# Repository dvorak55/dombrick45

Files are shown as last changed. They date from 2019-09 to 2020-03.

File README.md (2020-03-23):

# Dombrick45 : Dvorak Oriented 45% Keyboard
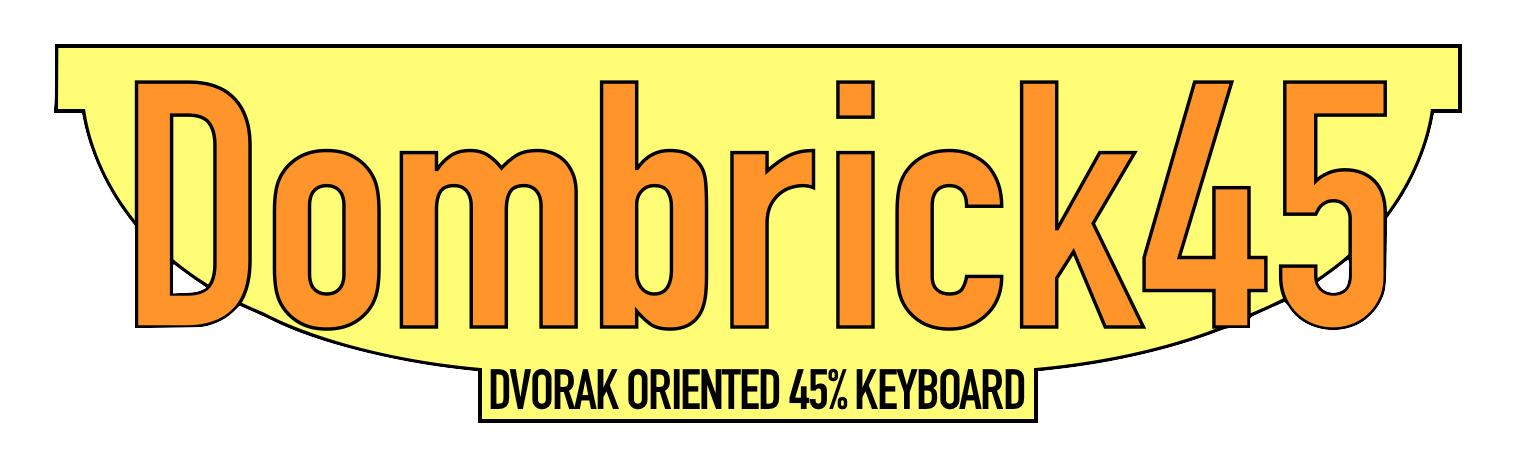
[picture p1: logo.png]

Dombrick45 is self made dvorak oriented keyboard.  
Dombrick45はDvorak配列志向の自作キーボードです。

"Dombrick" stands for Dvorak Oriented Mechanical Breakthough Remakable Interesting Coolest Keyboard (joke  
Dombrickという名前は「Dvorak志向の革新的で驚くべき大変興味深い最高にクールな機械式キーボード」を表す英単語の頭文字を取って命名しました（笑

Actually, "Dombri" means one of a japanese food style bowl, "ck" means nothing.  
嘘です、Dombriはもちろん日本語の丼を意味しており、ckの二文字はバランスを整えるために付けているだけです。

以下、[DescriptionのPDF](https://github.com/dvorak55/dombrick45/blob/master/description.pdf)から抜粋

## 概要
Dombrick45はコンパクトでシンプルな45％キーボードです。MCUもハンダ付けするタイプで比較的難易度は高め。QMK準拠、カスタマイズ可能。

## 特徴
- ボトムプレートがKitに含まれているため、キースイッチ・キーキャップとケーブルだけ揃えればキーボードが完成します
- 横幅13.25U、カーソルキーも搭載可能、USB Mini-BとUSB-Cの両対応
- 最下段キーがHotSwapで43keyから48keyまで好きに選べる。6.25uスペースバーも搭載可能
- ネジ締めは一切不要。モビロンバンドとシリコンマットによる全く新しいマウント方式なので組立しやすい
- ボトムプレートが重いので打鍵感が安定しています
- ATmega32U4やUSB-C端子のはんだ付けが必要。部品はすべて表面実装なので難易度は比較的高め
- 40%キーボード用キーキャップを使用(サンプルはGMK Jamón Forties)

## Kitに入っている部品
1. PCB 1枚
2. 電子部品(コンデンサ 7個、ダイオード 50個、フューズ 1個、抵抗 6個、ESDダイオード 1個、水晶振動子 1個、リセットスイッチ 1個)
3. MCU(ATmega32U4 1個)
4. USB端子(USB Mini-B 1個、USB-C 1個)
5. PCBソケット(Cherry MX互換 13個)
6. スタビライザー(2Uと6.25Uがそれぞれ 1個ずつ)
7. モビロンゴム(55mm 12本、100mm 6本)
8. シリコンシート(基板サイズ 2枚分)
9. ボトムプレート(厚さ2mmステンレス、基板サイズ 1枚)
10. プラスチックテープ(ソケットを隠すのに十分な長さ)
11. リセットスイッチを押す薄いプラ板

## 別途ご用意頂く部品
1. キースイッチ(Cherry MX互換で5ピンPCBマウント) 48個
2. キーキャップ
3. USBケーブル

## スペック（実装例）
サイズ：77mm × 253mm × 23mm

重さ　：約560グラム

## スイッチ互換性
Cherry MX互換とALPS(ただし最下段キーはCherry MX互換のみ)

## 写真等
### 実装例１
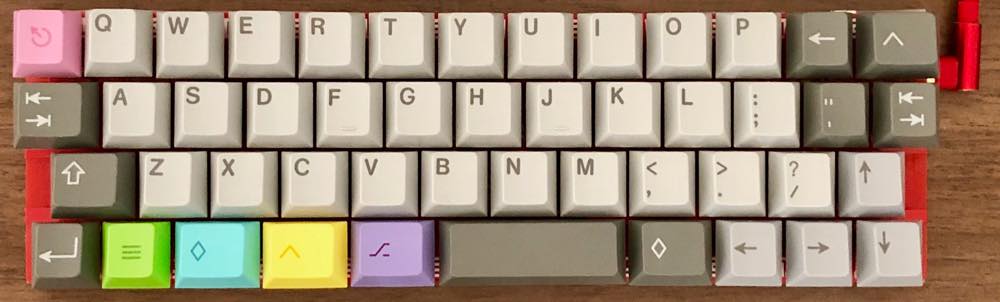
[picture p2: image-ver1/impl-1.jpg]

現在作者が使っているキー配列（48キー）。 GMK Paperworkを用いてさえ足りないキーキャップがある
### 実装例２
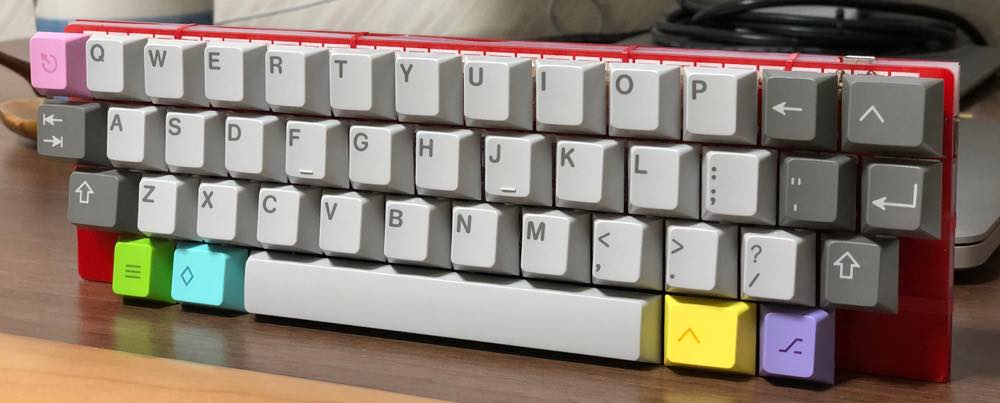
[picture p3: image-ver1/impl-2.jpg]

43キーしかない配列。6.25uのスペースバーを使えるようにしたかったんだ。

ちなみに最下段の両端のキーは取り外して、見えるはずの穴は赤色のプラスチックテープで巧妙に見えなくなっているので違和感が（多分）ないはず
### 実装例３
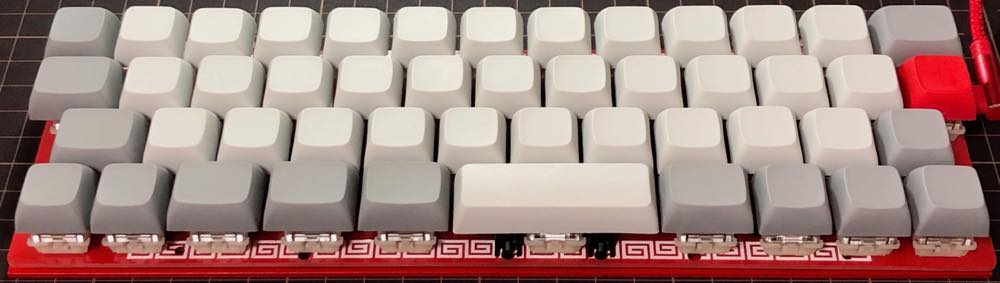
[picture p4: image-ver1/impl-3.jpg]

参考までに。無刻印は味気ない気がした。
### PCB基板（Ver.1かつJLCPCB版）
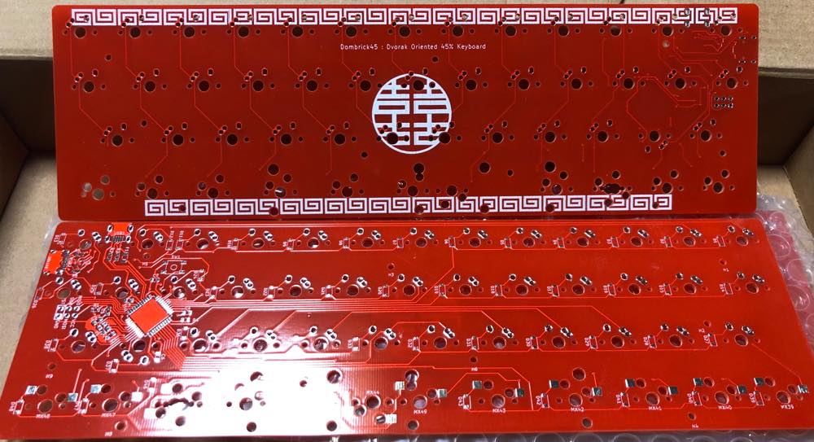
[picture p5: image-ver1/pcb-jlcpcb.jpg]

5枚のみ発注したJLCPCB版。ラーメンが食べたくなるでしょう？

Ver.1はこの5枚とALLPCBから届いた6枚、計11枚あります。
### スイッチ実装写真
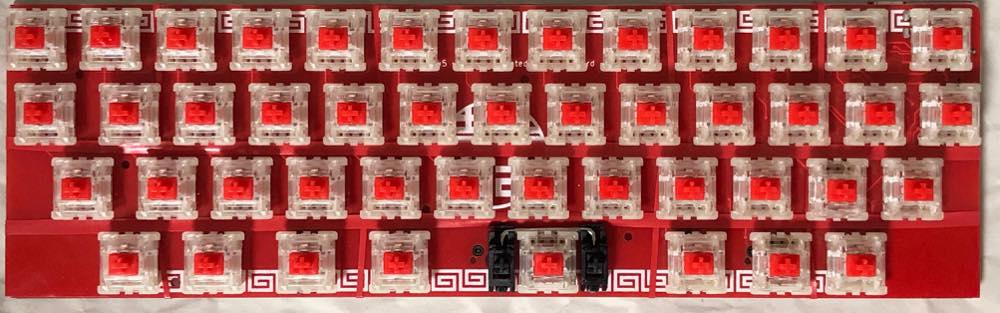
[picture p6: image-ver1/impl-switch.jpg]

右下と左下に赤色のプラスチックテープが貼ってあります。分かるかな〜

## Build Guide　ビルドガイド
部品をすべて実装するとこんな感じになります。
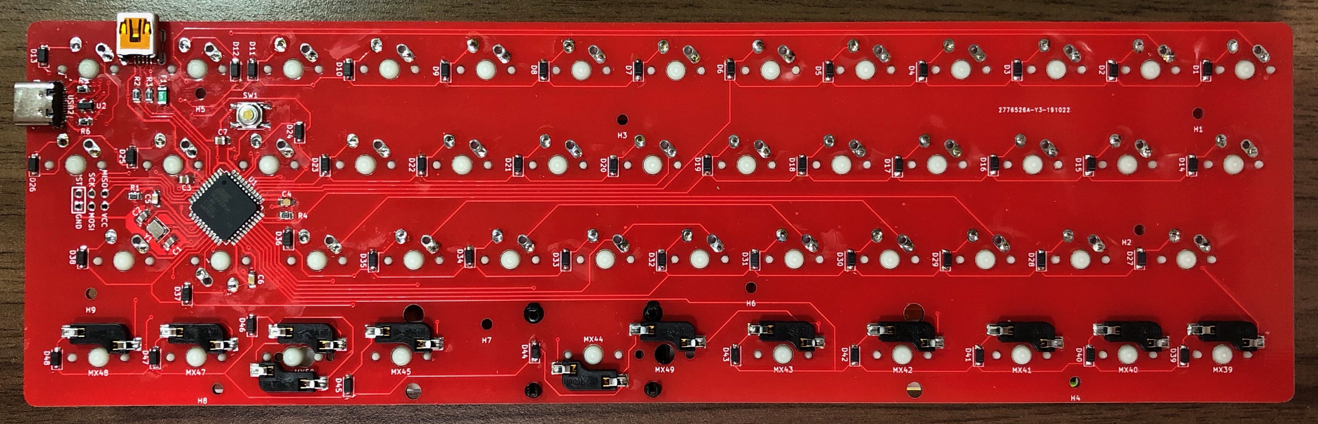
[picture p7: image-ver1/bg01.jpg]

さぁ、あなたの丼を実装する素晴らしい一日をスタートしましょう！

### 多分必要な道具
- はんだごて　30ワットあればOK
- ハンダを拭くスポンジとはんだごて置き場
- ハンダ吸い取り器、ハンダ吸い取り線
- 鉛フリーではない普通のハンダ
- 無洗浄フラックス
- フラックスを洗浄するアルコール的なもの（ケンエーIPAとか）
- ピンセットがあると最高に便利
- 導通確認やショート確認のためのテスター
- カッター
- カッターマット

### 実装手順
1. 以下にあげた表面実装部品を基板PCBにすべてはんだ付けします。Kitの部品にはすべて部品番号が明示されています。また、PCB基板上のはんだ付けする場所に部品番号が印刷されています。すなわち、部品番号ごとに取り出した部品を、その番号の書かれた場所にはんだ付けすればOKです。ここで実装する部品は、向きが関係無い部品、もしくは向きを間違える心配のない部品です。
   - コンデンサ 7個　C1〜C7
   - ヒューズ 1個　F1
   - 抵抗 6個　R1〜R6
   - リセットスイッチ 1個　※4つ足のスイッチ　SW1
   - USB端子 2個　※USB-CとUSB-MiniBの2種類　USB1、USB2
   - ESDダイオード 1個　※4つ足の黒い部品　1本だけ足が広い。基板実装箇所でも1箇所だけ足が広い。　U2  
部品をすべて実装した写真の拡大バージョンです。こちらも参考にしてください↓
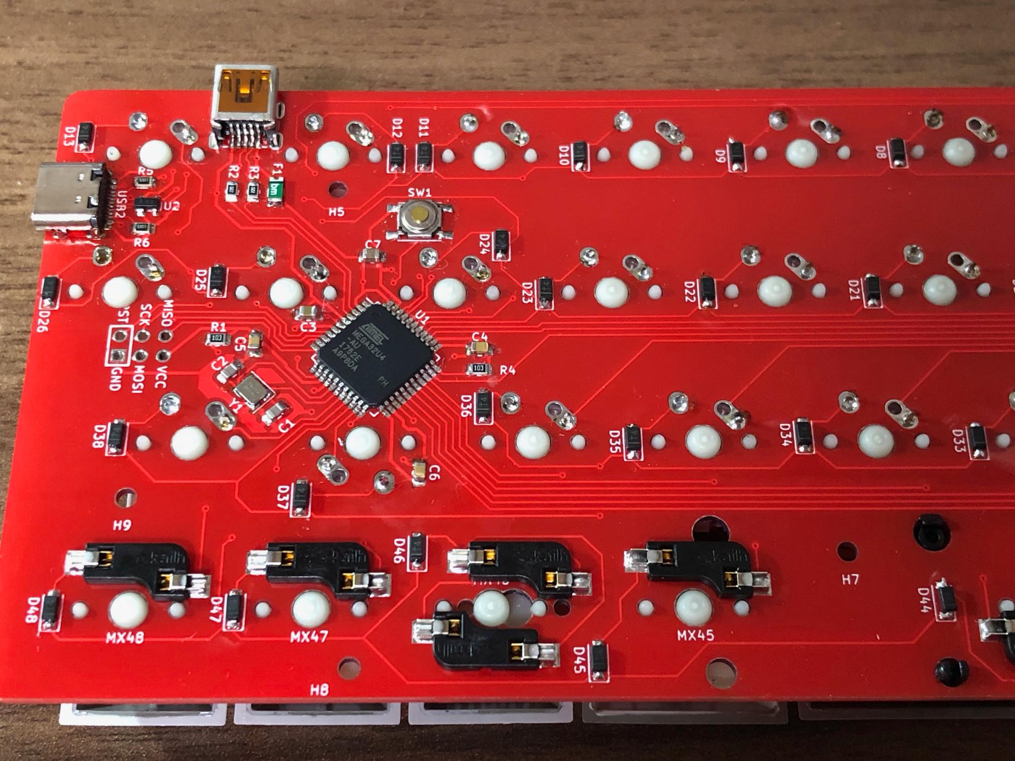
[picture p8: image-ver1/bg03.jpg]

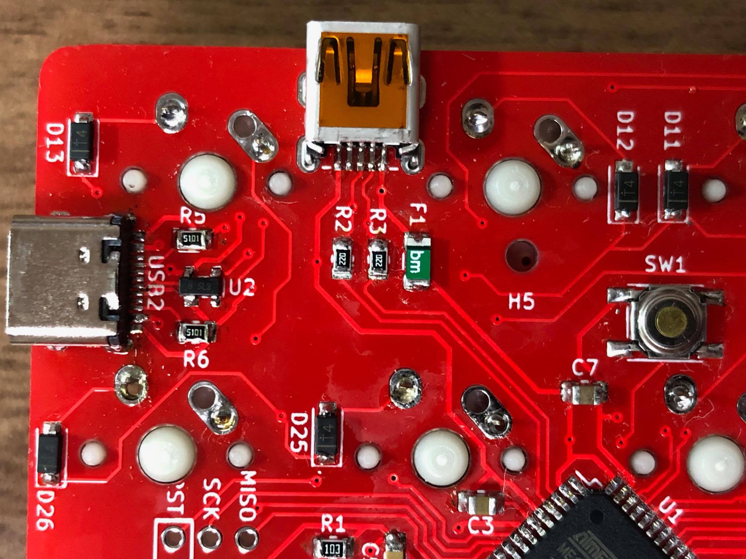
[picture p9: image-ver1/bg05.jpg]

2. MCU 1個と水晶振動子 1個をはんだ付けします。向きに注意。
   - MCUの○印の位置と、PCB基板上の⚡印の位置が同じになるようにします
   - 水晶振動子は非常にわかりにくいですが、MCUから見て文字が読める向きに付けます。
MCUと水晶振動子の向きは以下の写真も参照してください↓
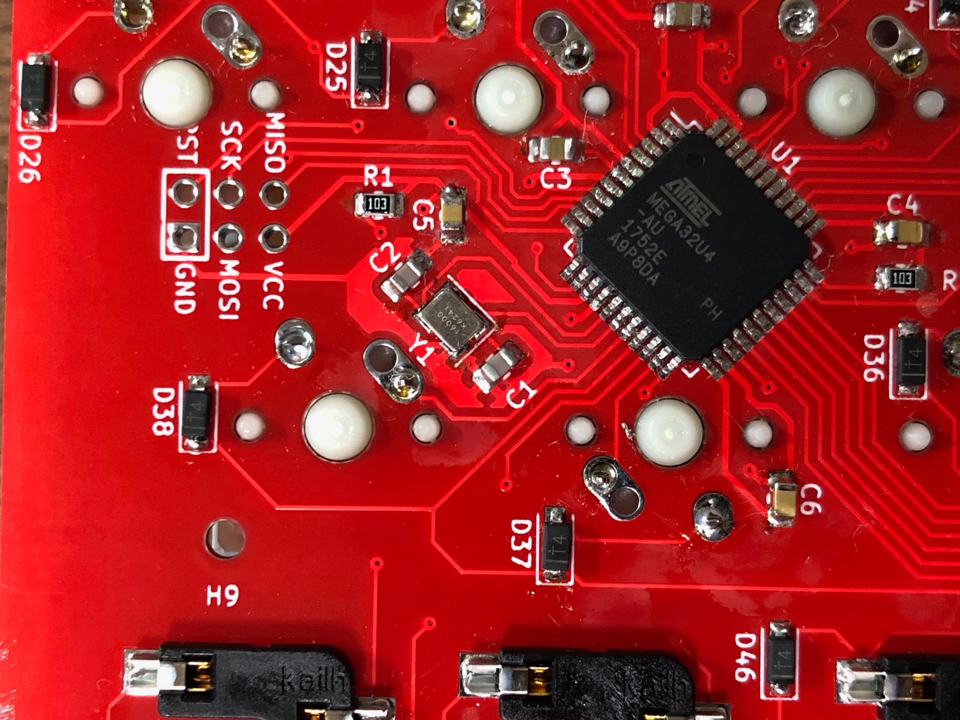
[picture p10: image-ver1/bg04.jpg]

3. 上記部品がはんだ付け終わったら、パソコンとUSBケーブルで接続し、Dombrick45のファームウェアが書き込めるかを確認します。書き込めれば次に進み、書き込めない or 認識されなければ、はんだ付けを修正します。  
※ファームウェアを書き込む方法はこちらを参照下さい→　https://github.com/dvorak55/dombrick45/tree/master/qmk
4. ダイオードをはんだ付けします。向きはすべて線の書いてある方向が下になるようにします。スペースバーのある方が下、USB-MiniB端子のある方が上です。2個余るはずです（2個は予備です）。向きは以下の写真も参考にしてください。
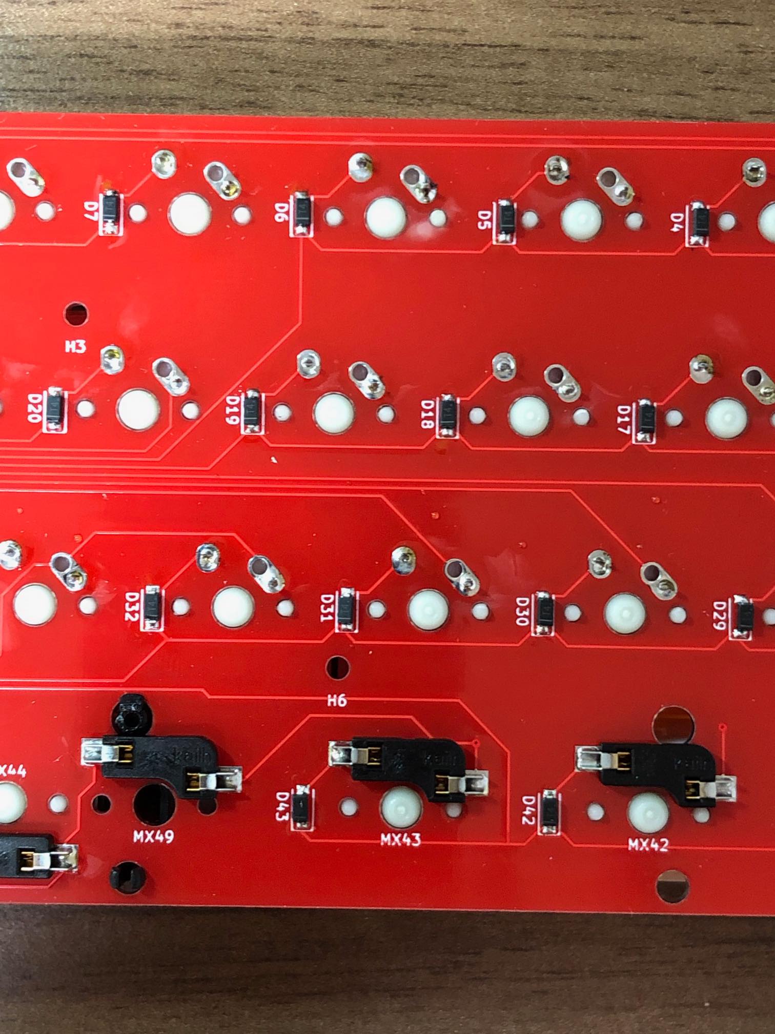
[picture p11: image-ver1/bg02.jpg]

5. PCBソケットをはんだ付けします。ソケットをPCB基板に差し込んでから、ハンダを付けてください。
6. 最後にキースイッチをはんだ付けします。
7. PCBソケットをはんだ付けした最下段にキースイッチを差し込みます。スペースバーのスタビライザーも取り付けます。
8. シリコンシートを基板のサイズに切り取ります。付属のシリコンシートから基板のサイズ2枚分取れます。これはPCB基板とボトムプレートの間に敷く衝撃吸収材兼絶縁材です。基板サイズのシリコンシートを2枚そのまま重ねるも良し、1枚を3分の2のところで分割し、上は3枚、中央は2枚、下は1枚と階段状にすることでキーボードに若干の角度を付けるも良し。
シリコンシートは付属のボトムプレートのサイズに切り取ります。
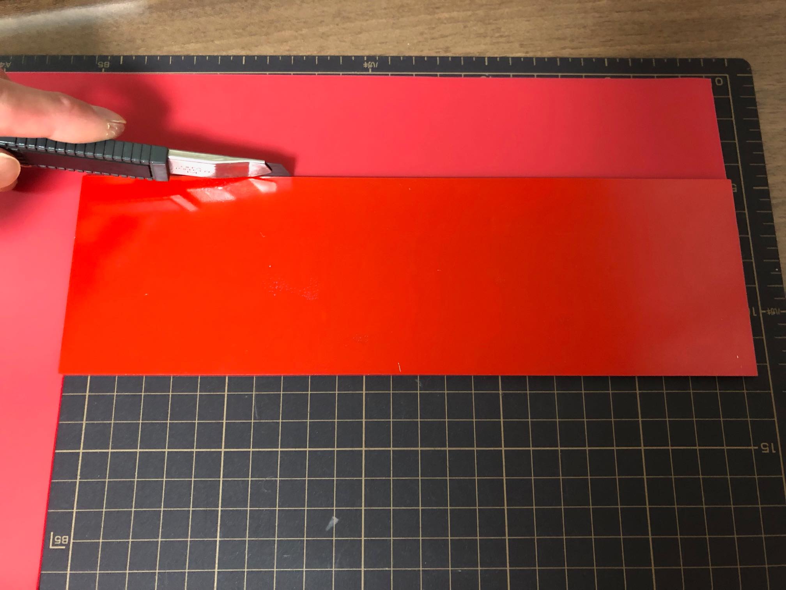
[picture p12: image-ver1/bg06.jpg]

USB端子のある場所は、シリコンシートに切り欠けを作り、端子が干渉しないようにします。
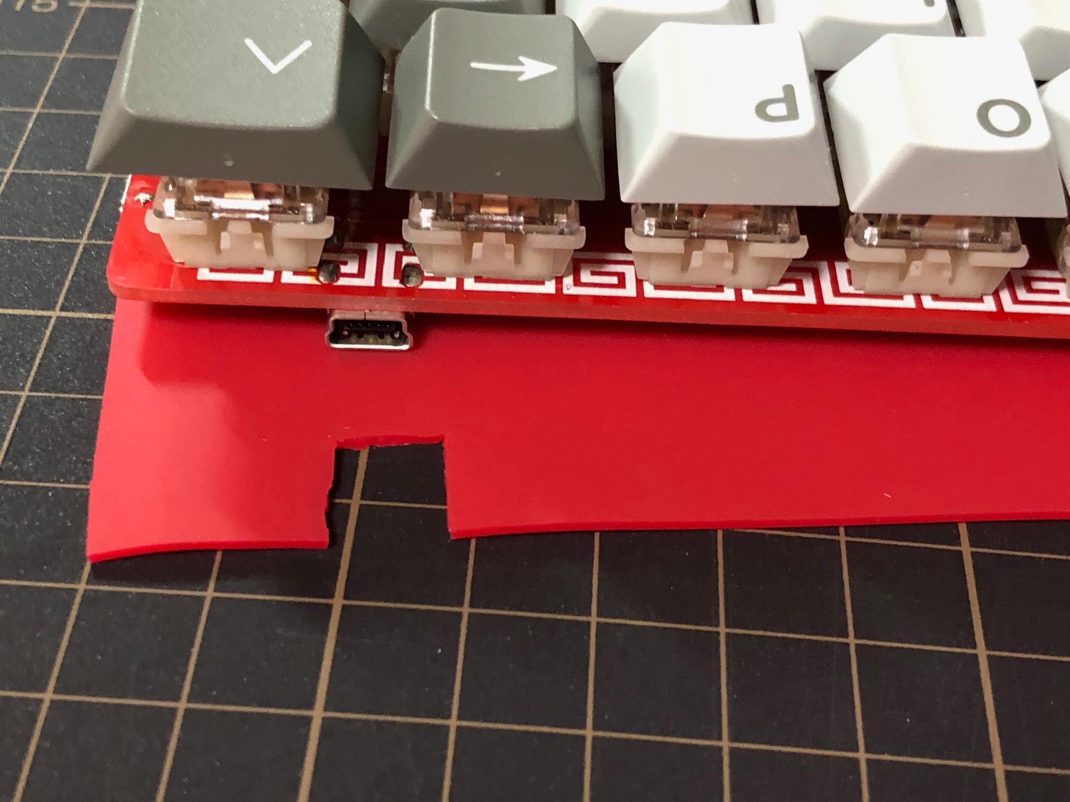
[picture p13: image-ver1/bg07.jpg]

2枚分のシリコンシートを階段状にする場合、以下のように切り欠けが重なるようにします。
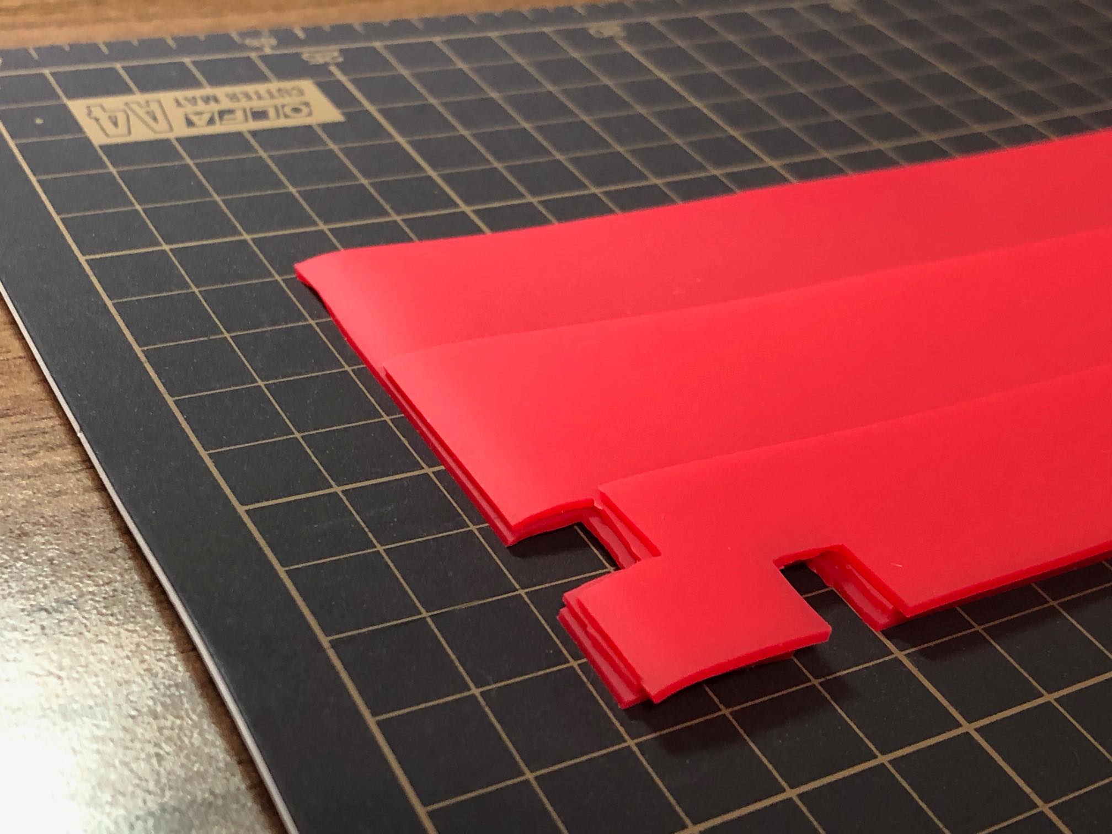
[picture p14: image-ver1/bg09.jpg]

このままだとリセットスイッチとシリコンシートが干渉し、強くキーを押すとリセットスイッチが押されてしまいます。そこで、リセットスイッチの位置（以下の画像の白い所）にも切り欠けを作ります。これは一番上に重ねたシートのみでOKです。
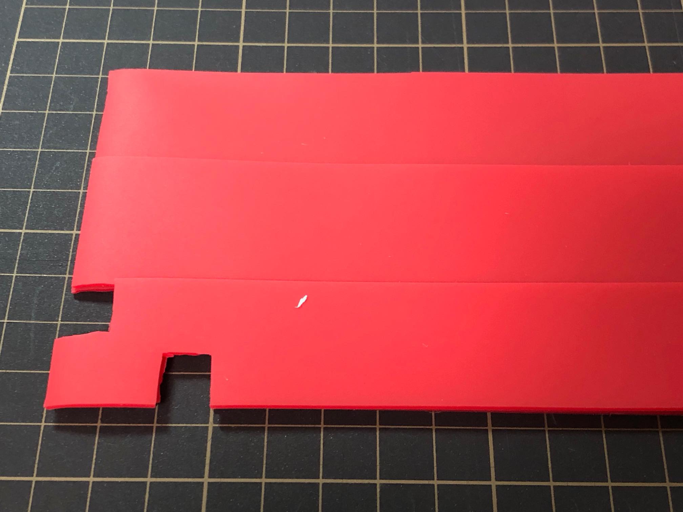
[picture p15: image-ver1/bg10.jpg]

切り欠けを作ったシート
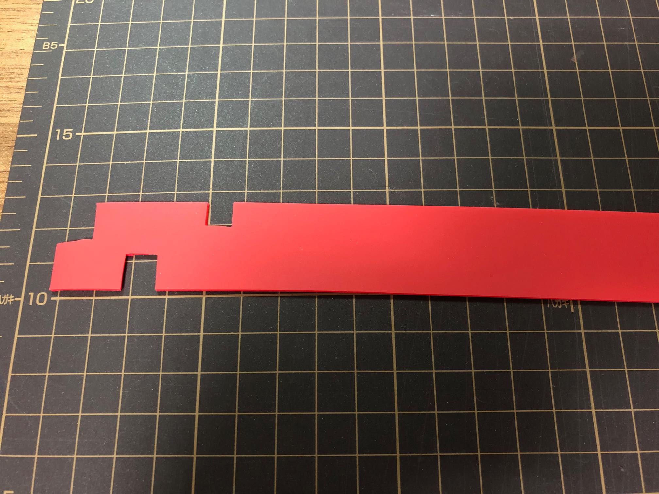
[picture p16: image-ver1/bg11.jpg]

最終的にできたシートを重ねた状態
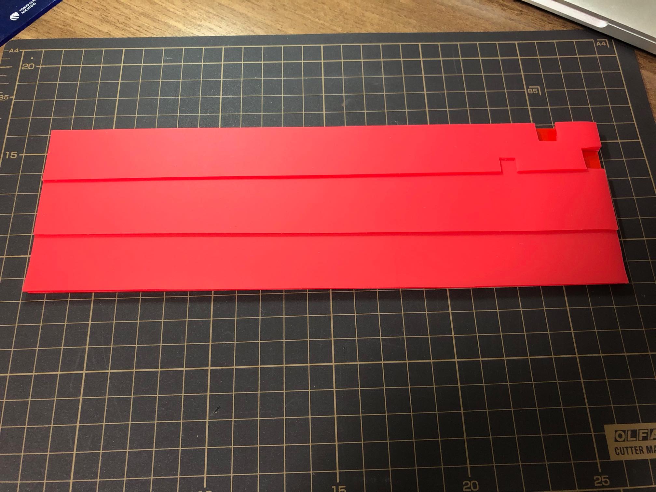
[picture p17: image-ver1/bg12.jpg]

9. 基板・シリコンシート・ボトムプレートを重ねます。
10. それらをモビロンゴムでまとめます。短いモビロンゴムは縦方向、長いモビロンゴムは横方向をとめます。うまくキースイッチの間に入るようにゴムを調整します。短いゴムは4本、長いゴムは2本で足ります。残りは予備です。このゴムは滑り止めにもなっています。  
ゴムは以下の写真の線のところに配置すると良さげです。横方向の一番上はあってもなくても大丈夫です。
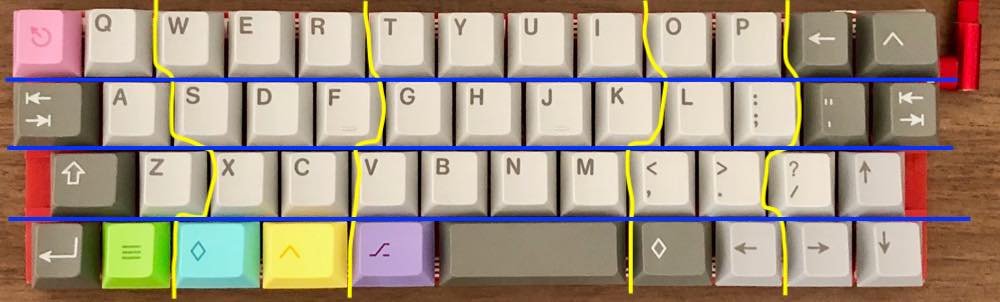
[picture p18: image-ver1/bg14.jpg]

短いゴムはそのまま付けるだけだとキーキャップに干渉します。
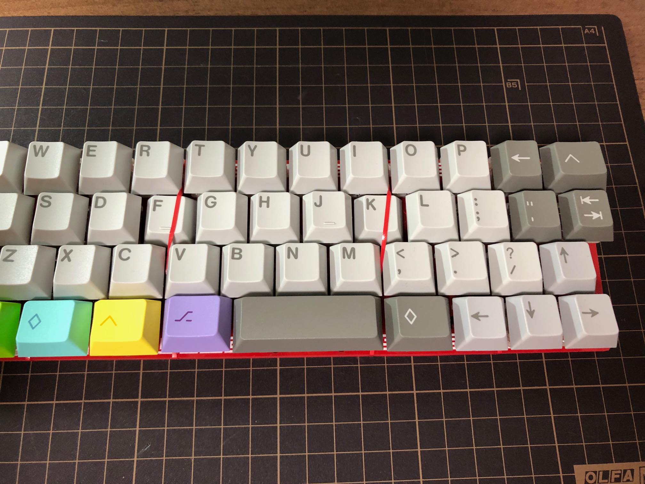
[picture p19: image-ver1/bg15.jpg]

適当なキーキャップを取り外し、
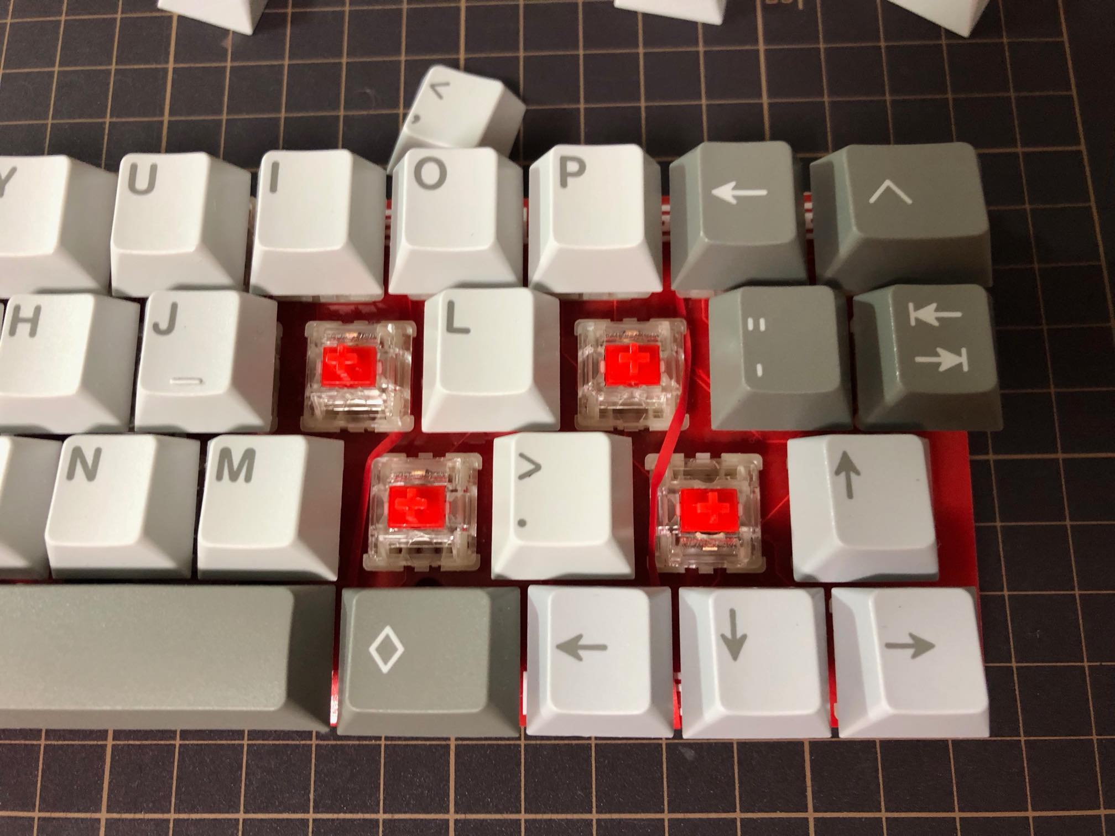
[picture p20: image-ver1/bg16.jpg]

先の尖っていない細い棒等でモビロンゴムを一番下まで突っつきます。
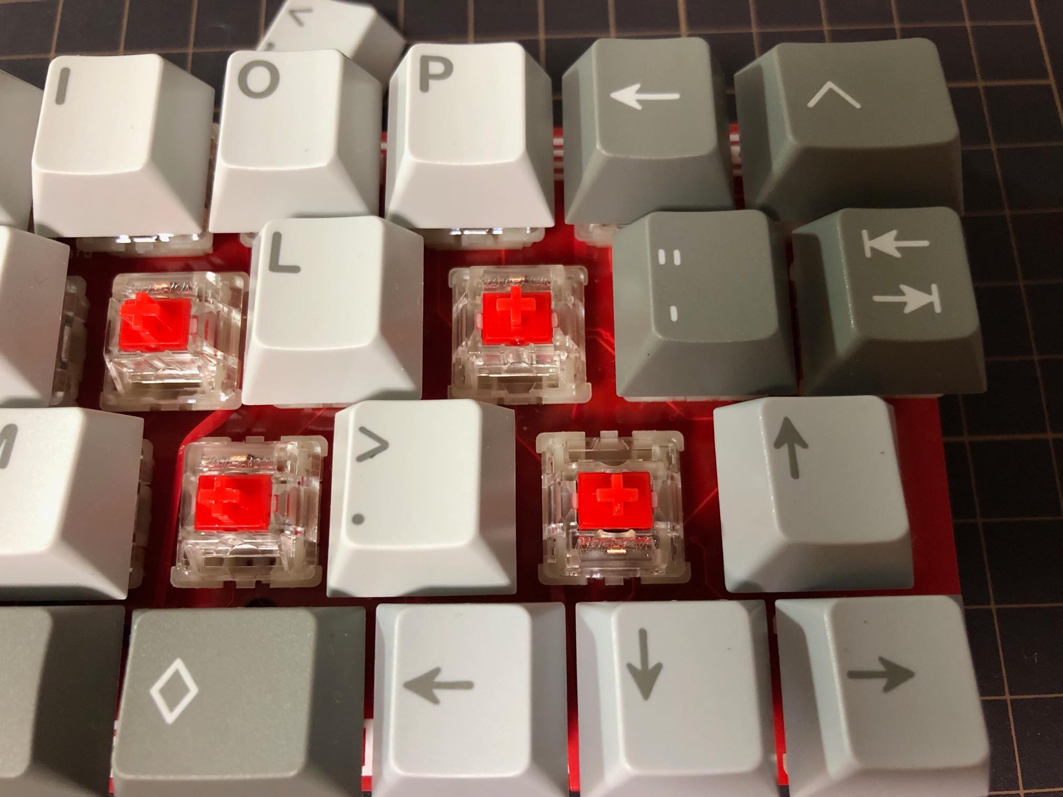
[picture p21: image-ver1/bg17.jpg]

4箇所ともゴムをきちんと一番下まで入れます。
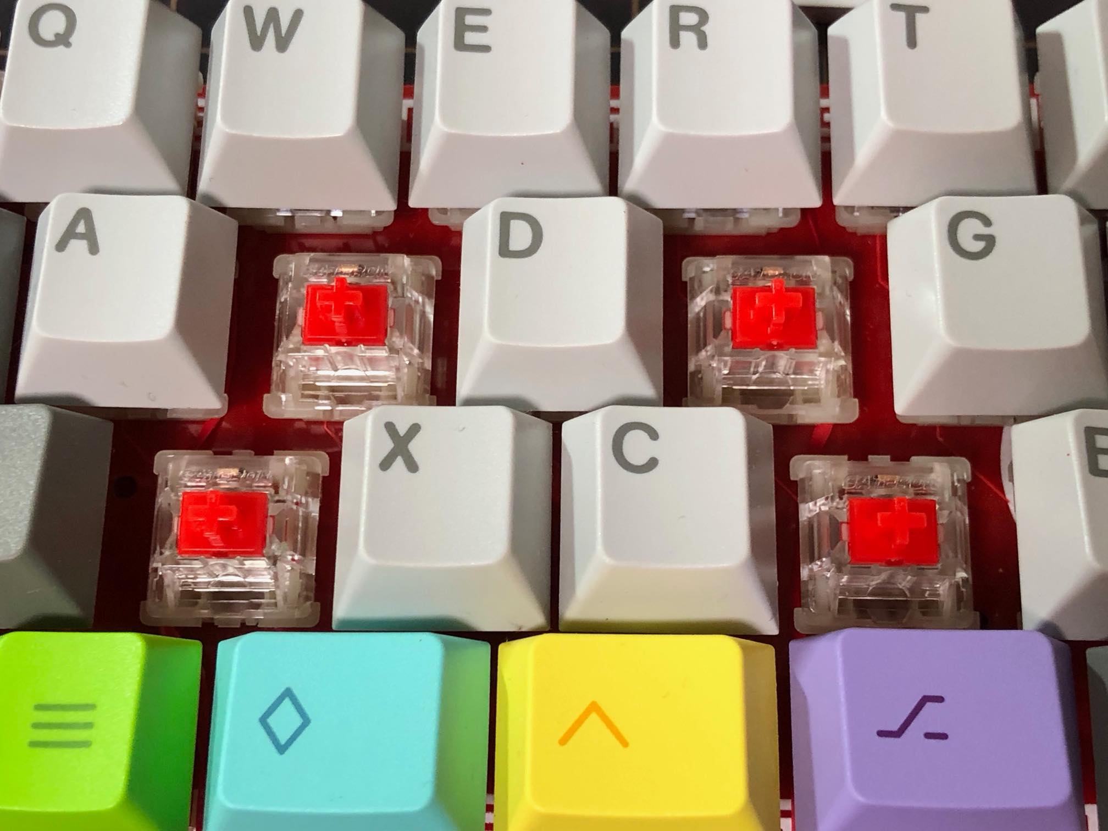
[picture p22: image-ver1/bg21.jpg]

横方向のゴムを付けるのは簡単だと思います。3本付けるとこのようになります。
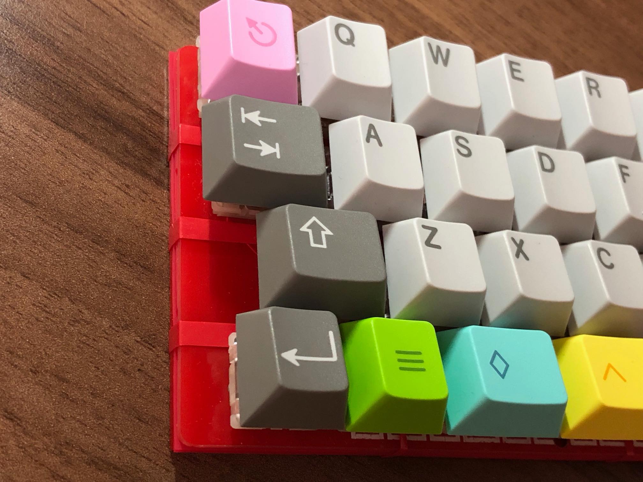
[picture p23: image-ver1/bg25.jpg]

11. お好きなキーキャップを取り付けます
12. もし43キーか46キーのキーマップを実装していた場合、最下段両端のキーソケットと穴を隠すために、Kitの袋に貼り付いている赤色のプラスチックテープを適当に切りPCB基板の最下段両端部分を隠すように貼ります。
13. お好きなUSBケーブルでパソコンに接続します
14. リセットスイッチが右手小指辺りにあります。リセットスイッチを押すための薄いプラ板をシリコンシートとPCB基板の間に挿入し、リセットスイッチを押してください  
この辺りに板を差し込みます。
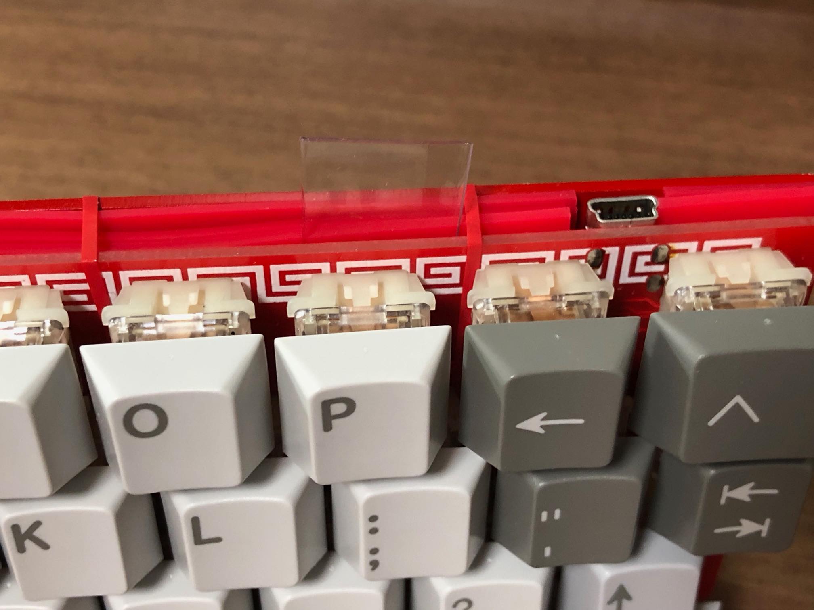
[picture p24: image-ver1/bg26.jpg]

リセットスイッチは以下の写真の黄色丸の位置にあります。板をこの辺りにまで差し込み、キーボードを押してリセットスイッチを押します。
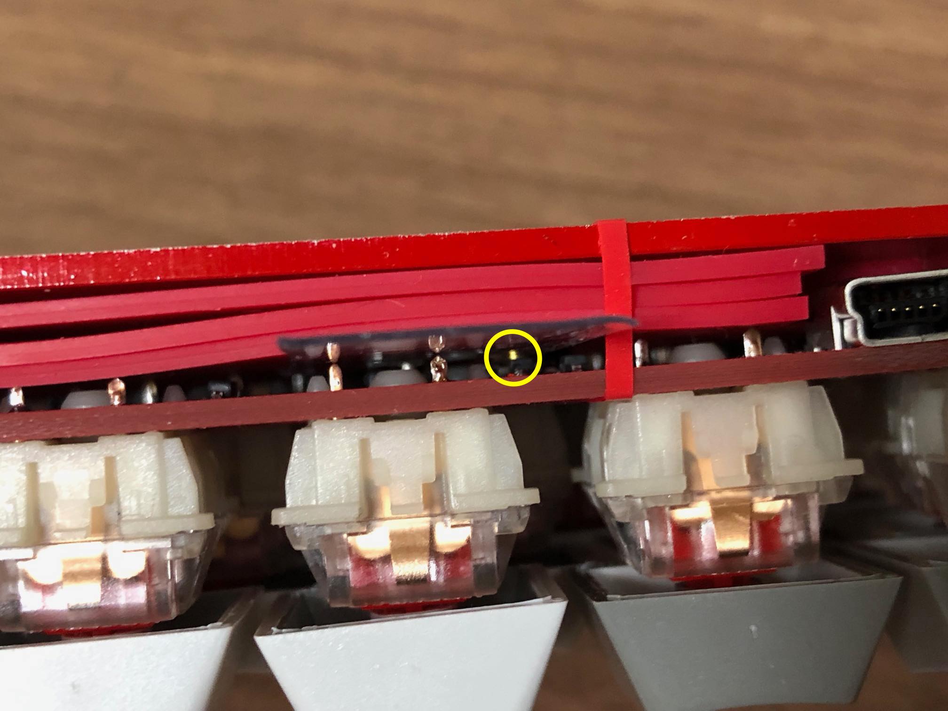
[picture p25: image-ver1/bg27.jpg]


15. リセットスイッチを押したら、ファームウェアを書き込み、動作確認を行う  
ファームウェアを書き込む方法はこちらを参照下さい→　https://github.com/dvorak55/dombrick45/tree/master/qmk

### 完成です！
楽しい丼生活をエンジョイしてください！

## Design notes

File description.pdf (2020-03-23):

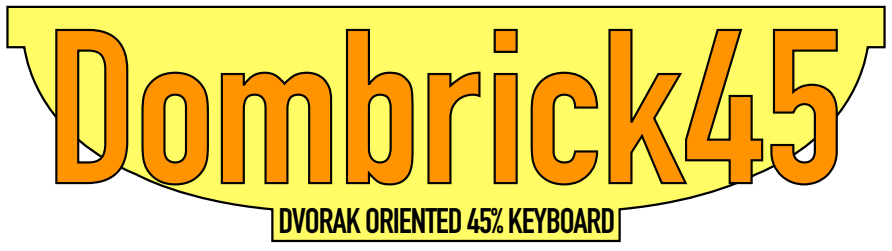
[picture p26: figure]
Dombrick45; DVORAK ORIENTED 45% KEYBOARD

# Dombrick45はコンパクトでシンプルな45％キーボー ドです。MCUもハンダ付けするタイプで⽐較的難易 度は⾼め。QMK準拠、カスタマイズ可能。

## Dombrick45の特徴

- ボトムプレートがKitに含まれているため、キースイッチ・キーキャップ とケーブルだけ揃えればキーボードが完成します - 横幅13.25U、カーソルキーも搭載可能、USBMini-BとUSB-Cの両対応 - 最下段キーがHotSwapで43keyから48keyまで好きに選べる。6.25uスペー スバーも搭載可能 - ネジ締めは⼀切不要。モビロンバンドとシリコンマットによる全く新しい マウント⽅式なので組⽴しやすい - ボトムプレートが重いので打鍵感が安定しています - ATmega32U4やUSB-C端⼦のはんだ付けが必要。部品はすべて表⾯実装な ので難易度は⽐較的⾼め - 40%キーボード⽤キーキャップを使⽤(サンプルはGMKJamónForties)

### Dombrick45Kitに⼊っている部品

1. PCB1枚
2. 電⼦部品(コンデンサ7個、ダイオード50個、フューズ1 個、抵抗6個、ESDダイオード1個、⽔晶振動⼦1個、 リセットスイッチ1個)
3. MCU(ATmega32U41個)
4. USB端⼦(USBMini-B1個、USB-C1個)
5. PCBソケット(CherryMX互換13個)
6. スタビライザー(2Uと6.25Uがそれぞれ1個ずつ)
7. モビロンゴム(55mm12本、100mm6本)
8. シリコンシート(基板サイズ2枚分)
9. ボトムプレート(厚さ2mmステンレス、基板サイズ1枚)
10. プラスチックテープ(ソケットを隠すのに⼗分な⻑さ)
11. リセットスイッチを押す薄いプラ板

### 別途ご⽤意頂く部品

1. キースイッチ(CherryMX互換で5ピンPCBマウント)48個
2. キーキャップ
3. USBケーブル

### スペック(実装例)

サイズ：77mm×253mm×23mm
重さ ：約560グラム

### スイッチ互換性

CherryMX互換とALPS(ただし最下
段キーはCherryMX互換のみ)

### 実装⼿順書

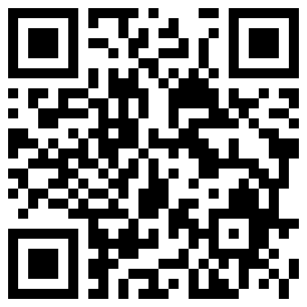
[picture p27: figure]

https://github.com/dvorak55/dombrick45

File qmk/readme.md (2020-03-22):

# Dombrick45 キー配列一覧と、キー配列の書き込み方法

Dombrick45には通常のQWERTY配列以外にもDvorak配列のキー配列が存在します。  
また、スペースバーが2種類搭載可能だったり、丼配列と称して右下・左下のキーを隠す配列も存在したりするので、キー数は4種類選べます。  
配列が2種類、とキー数が4種類、かけ合わせると8種類のキー配列になります。実装が大変。  

ただ、レイヤー1・レイヤー2による記号・数字・ファンクションキーの入力は、全てのキー配列で同一です。  
キー配列の画像はこちらです。  

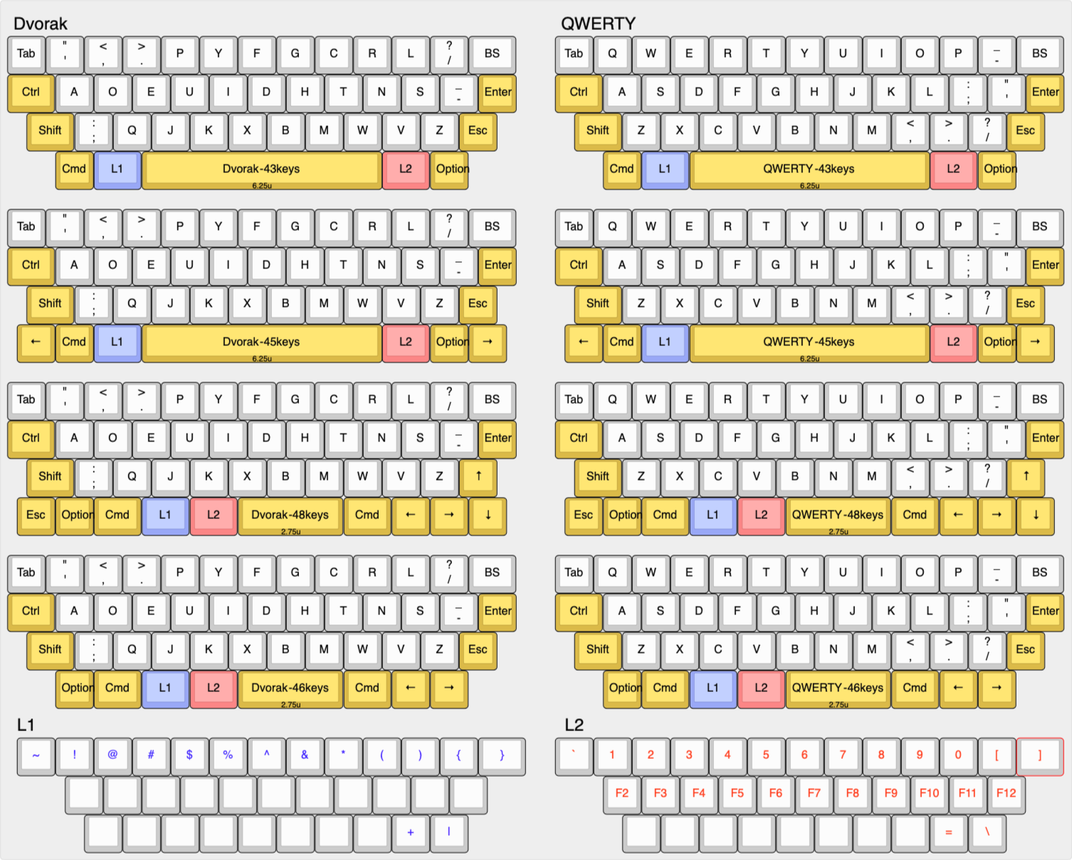
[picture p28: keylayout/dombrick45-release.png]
dombrick45-release


この8種類のキー配列であれば、簡単にキーボードに配列を書き込めるようにしました。  

## キー配列の書き込み方法
1. 好きなキー配列を選び、そのとおりにキーボードを実装する
2. そのキー配列のHEXファイルをダウンロードする  
この場所にキー配列のHEXファイルがありますので、好きなものをダウンロードして下さい。  
https://github.com/dvorak55/dombrick45/tree/master/qmk/hex

Dvorak配列のHEXファイル  
- dombrick45_dvorak-43keys.hex
- dombrick45_dvorak-45keys.hex
- dombrick45_dvorak-46keys.hex
- dombrick45_dvorak-48keys.hex

QWERTY配列のHEXファイル  
- dombrick45_qwerty-43keys.hex
- dombrick45_qwerty-45keys.hex
- dombrick45_qwerty-46keys.hex
- dombrick45_qwerty-48keys.hex
※これ以外のHEXファイルもありますが、それは作者がカスタマイズしたものです。  
3. QMK Toolboxをパソコンにインストールする  
サリチル酸氏のサイトが大変分かりやすいです。感謝。    
https://salicylic-acid3.hatenablog.com/entry/qmk-toolbox
4. QMK Toolboxを起動して、Dombrick45の基板をパソコンに接続する
5. Dombrick45のリセットボタンを押す
6. QMK ToolboxにダウンロードしたHEXファイルを読み込ませる
7. Microcontrollerを atmega32U4 にする
8. Flashする
9. 完了

## キー配列のカスタマイズ方法
以下のようにします。  
1. QMKをパソコンにインストールします。
2. Dombrick45のキーマップをダウンロードします。
こちらにあります。  
https://github.com/dvorak55/dombrick45/tree/master/qmk/keymaps
3. 独自のキーマップフォルダを作成し、Dombrick45のキーマップをコピーします
4. コピーしたキーマップを自分好みに編集します
5. 編集したら、コマンドラインで make Dombrick45 を実行してHEXファイルを作成します
※詳細はGoogleで QMK カスタマイズ と検索すると手順が出てきますので、参照して下さい

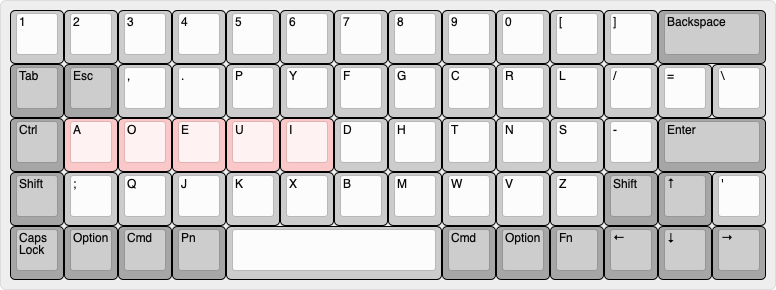
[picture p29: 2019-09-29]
keylayout/risouno-dvorak63.png

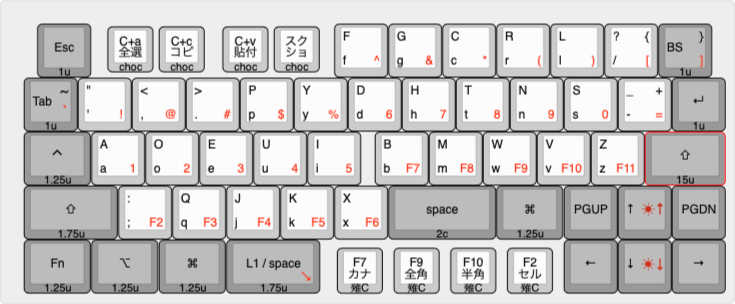
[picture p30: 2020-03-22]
keylayout/endgame-dvorak13-2.png

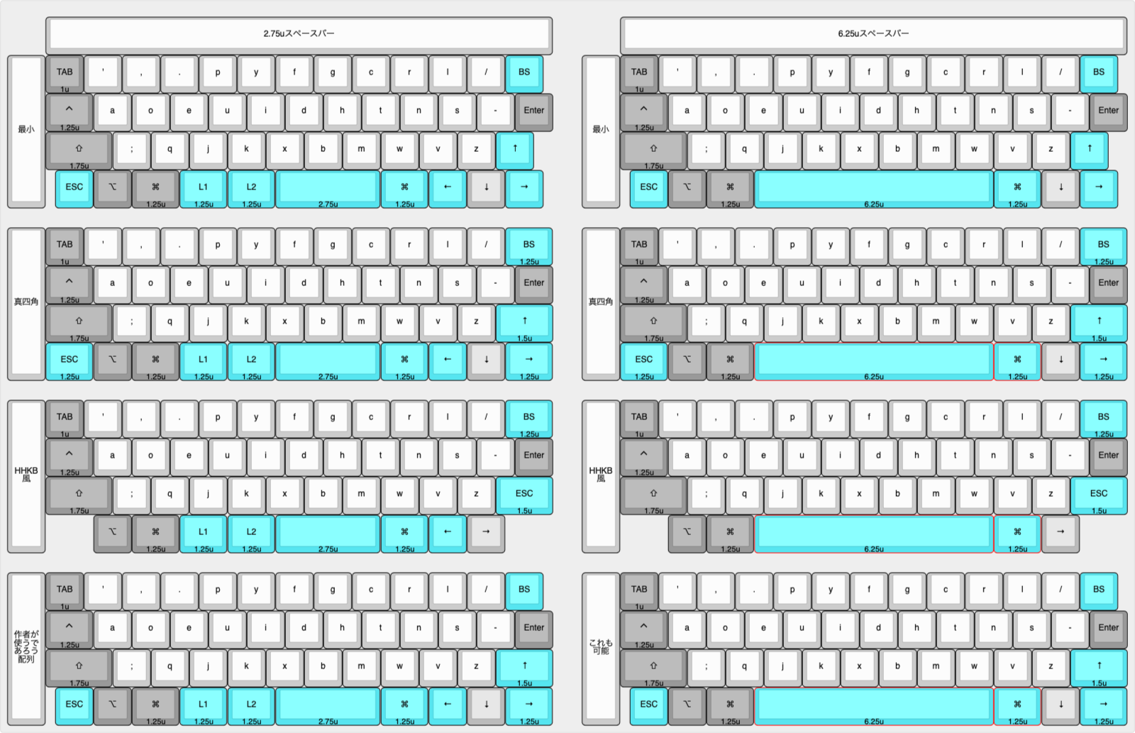
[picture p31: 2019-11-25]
keylayout/endgame-dvorak11-1.png

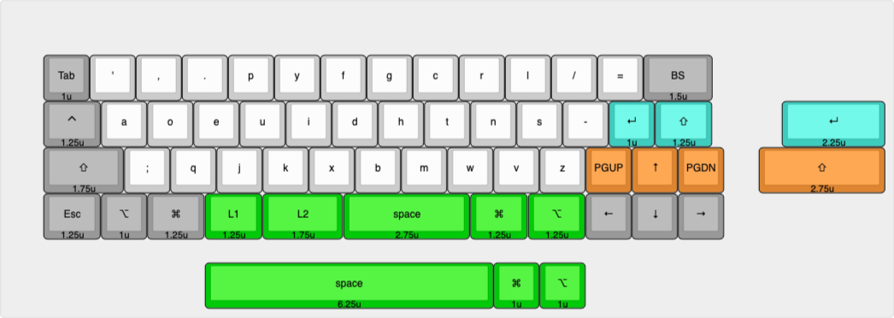
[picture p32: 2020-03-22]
keylayout/endgame-dvorak12-1.png

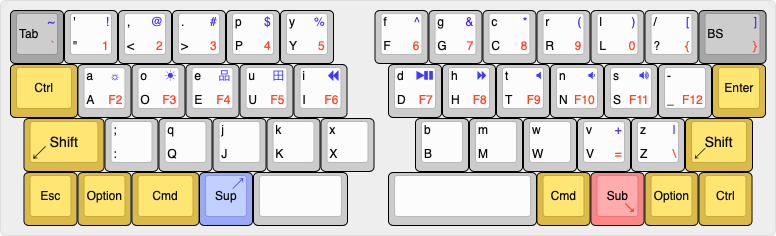
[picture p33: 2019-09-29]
keylayout/endgame-dvorak7-1-split.png

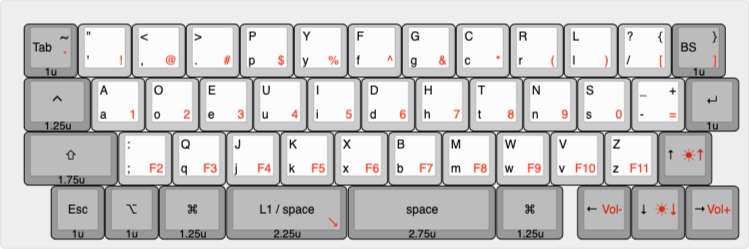
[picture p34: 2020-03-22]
qmk/keymaps/t-miyajima2/endgame-dvorak11-5.png

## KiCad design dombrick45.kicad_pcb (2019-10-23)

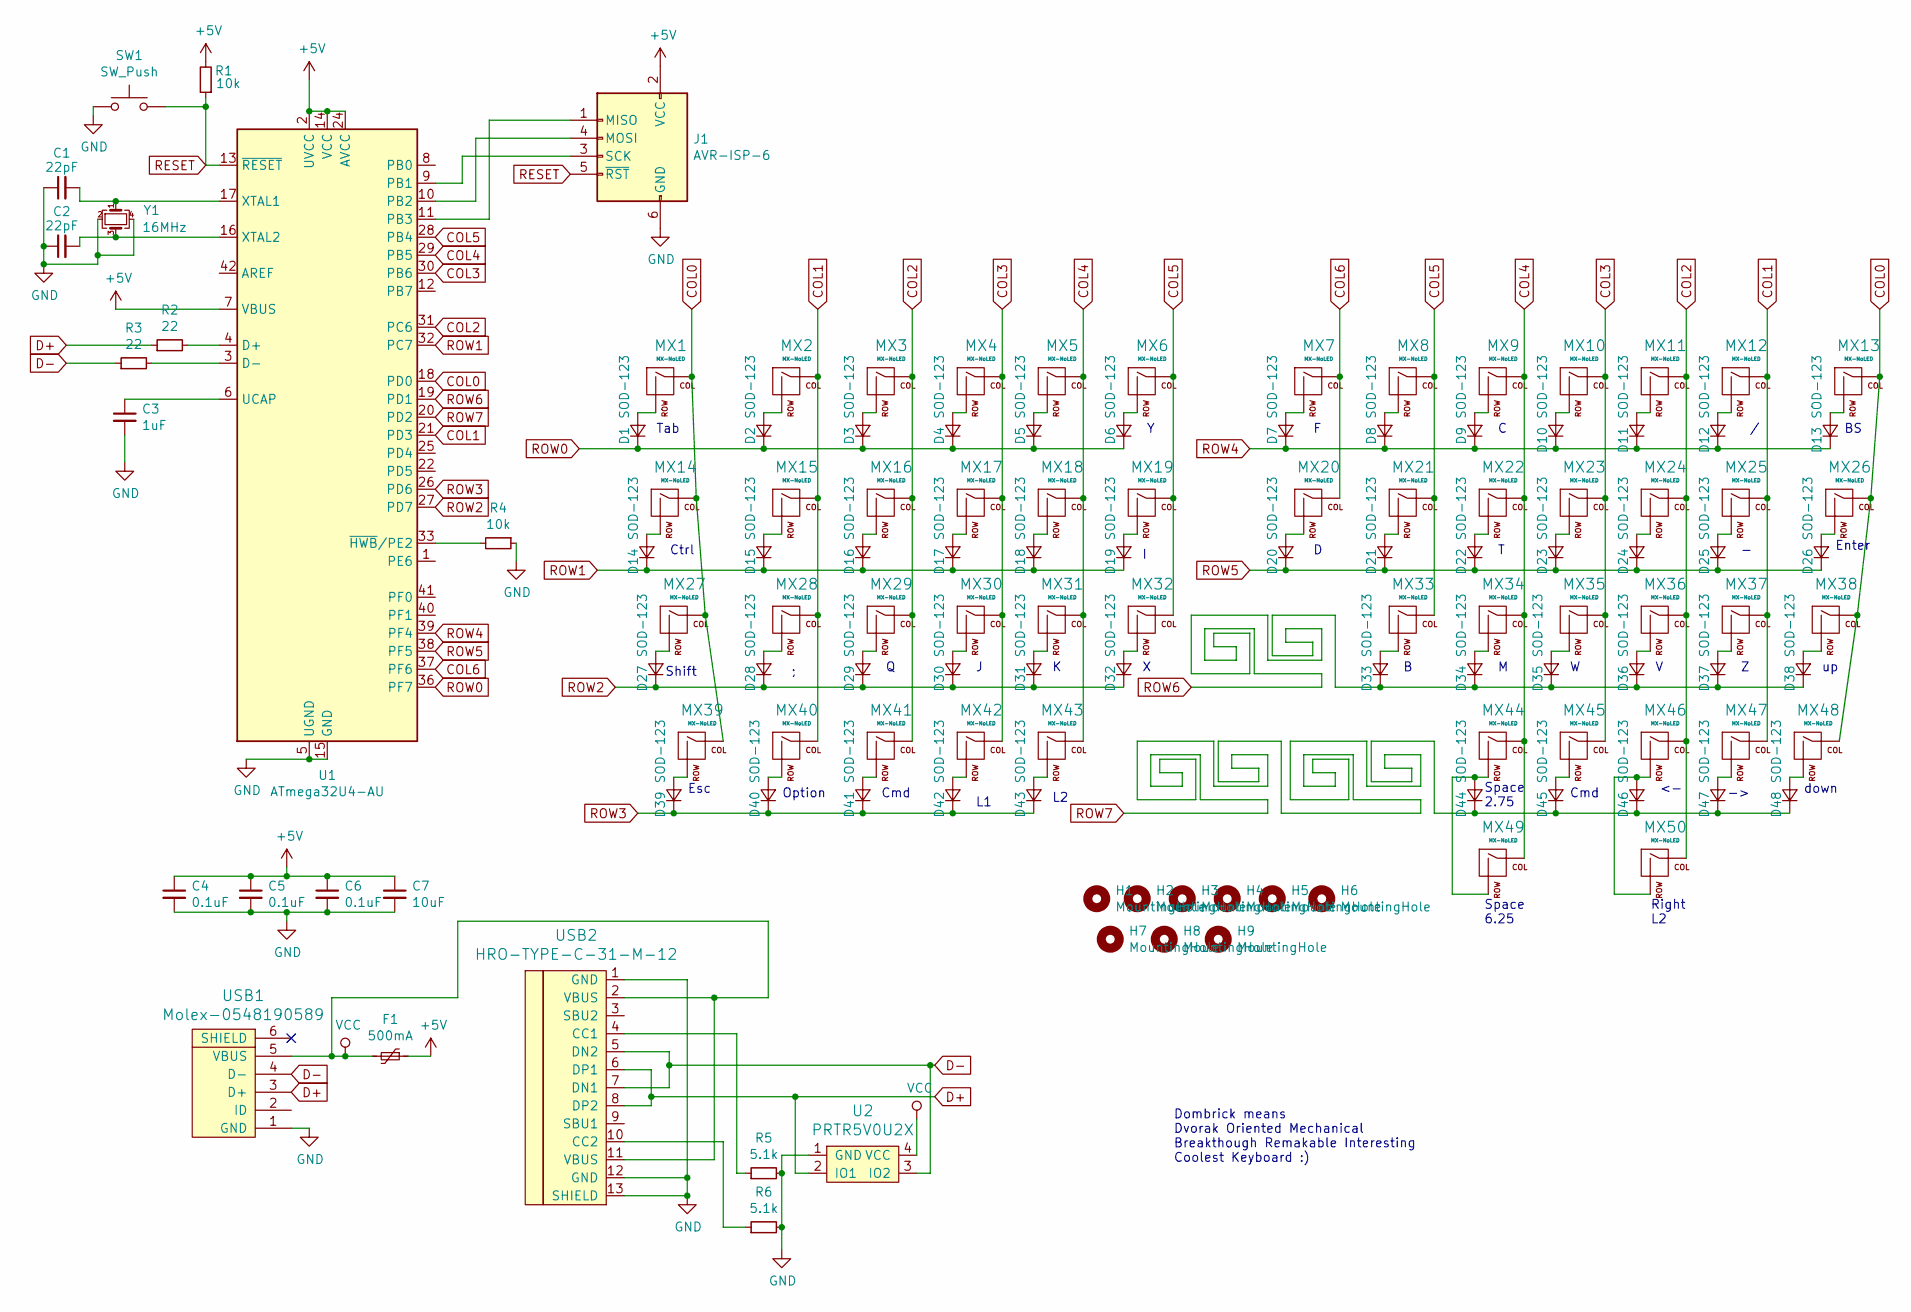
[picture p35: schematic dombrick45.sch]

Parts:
C1, C2: 22pF; C_0805_2012Metric_Pad1.15x1.40mm_HandSolder
C3: 1uF; C_0805_2012Metric_Pad1.15x1.40mm_HandSolder
C4, C5, C6: 0.1uF; C_0805_2012Metric_Pad1.15x1.40mm_HandSolder
C7: 10uF; C_0805_2012Metric_Pad1.15x1.40mm_HandSolder
D1, D2, D3, D4, D5, D6, D7, D8, D9, D10, D11, D12, D13, D14, D15, D16, D17, D18, D19, D20, D21, D22, D23, D24, D25, D26, D27, D28, D29, D30, D31, D32, D33, D34, D35, D36, D37, D38, D39, D40, D41, D42, D43, D44, D45, D46, D47, D48: SOD-123; D_SOD-123
F1: 500mA; Fuse_1206_3216Metric
H1, H2, H3, H4, H5, H6, H7, H8, H9: MountingHole; MountingHole_2.2mm_M2
J1: AVR-ISP-6; Reset_Pretty
MX1, MX2, MX3, MX4, MX5, MX6, MX7, MX8, MX9, MX10, MX11, MX12, MX15, MX16, MX17, MX18, MX19, MX20, MX21, MX22, MX23, MX24, MX25, MX26, MX28, MX29, MX30, MX31, MX32, MX33, MX34, MX35, MX36, MX37, MX38: MX-NoLED; MX-1U-NoLED
MX13, MX14, MX27: MX-NoLED; MX-1.25U-NoLED
MX39, MX40, MX46, MX47, MX48: MX-NoLED; MXOnly-1U-Hotswap
MX41, MX42, MX43, MX45, MX50: MX-NoLED; MXOnly-1.25U-Hotswap
MX44: MX-NoLED; MXOnly-2.75U-Hotswap
MX49: MX-NoLED; MXOnly-6.25U-Hotswap-ReversedStabilizers
R1, R4: 10k; R_0805_2012Metric
R2, R3: 22; R_0805_2012Metric
R5, R6: 5.1k; R_0805_2012Metric
SW1: SW_Push; SKQG-1155865
U1: ATmega32U4-AU; TQFP-44_10x10mm_P0.8mm
U2: PRTR5V0U2X; SOT143B
USB1: Molex-0548190589
USB2: HRO-TYPE-C-31-M-12; HRO-TYPE-C-31-M-12-Assembly
Y1: 16MHz; Crystal_SMD_3225-4Pin_3.2x2.5mm

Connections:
+5V: C4.1, C5.1, C6.1, C7.1, F1.1, J1.2 (VCC), R1.2, U1.2 (UVCC), U1.7 (VBUS), U1.14 (VCC), U1.24 (AVCC), U1.34 (VCC), U1.44 (AVCC)
COL0: MX1.1 (COL), MX13.1 (COL), MX14.1 (COL), MX26.1 (COL), MX27.1 (COL), MX38.1 (COL), MX39.1 (COL), MX48.1 (COL), U1.18 (PD0)
COL1: MX2.1 (COL), MX12.1 (COL), MX15.1 (COL), MX25.1 (COL), MX28.1 (COL), MX37.1 (COL), MX40.1 (COL), MX47.1 (COL), U1.21 (PD3)
COL2: MX3.1 (COL), MX11.1 (COL), MX16.1 (COL), MX24.1 (COL), MX29.1 (COL), MX36.1 (COL), MX41.1 (COL), MX46.1 (COL), MX50.1 (COL), U1.31 (PC6)
COL3: MX4.1 (COL), MX10.1 (COL), MX17.1 (COL), MX23.1 (COL), MX30.1 (COL), MX35.1 (COL), MX42.1 (COL), MX45.1 (COL), U1.30 (PB6)
COL4: MX5.1 (COL), MX9.1 (COL), MX18.1 (COL), MX22.1 (COL), MX31.1 (COL), MX34.1 (COL), MX43.1 (COL), MX44.1 (COL), MX49.1 (COL), U1.29 (PB5)
COL5: MX6.1 (COL), MX8.1 (COL), MX19.1 (COL), MX21.1 (COL), MX32.1 (COL), MX33.1 (COL), U1.28 (PB4)
COL6: MX7.1 (COL), MX20.1 (COL), U1.37 (PF6)
D+: R2.1, U2.2 (IO1), USB1.3 (D+), USB2.6 (DP1), USB2.8 (DP2)
D-: R3.1, U2.3 (IO2), USB1.4 (D-), USB2.5 (DN2), USB2.7 (DN1)
GND: C1.1, C2.1, C3.2, C4.2, C5.2, C6.2, C7.2, J1.6 (GND), R4.1, R5.2, R6.2, SW1.1, U1.5 (UGND), U1.15 (GND), U1.23 (GND), U1.35 (GND), U1.43 (GND), U2.1 (GND), USB1.1 (GND), USB2.1 (GND), USB2.12 (GND), USB2.13 (SHIELD), Y1.2, Y1.4
unnamed: C1.2, U1.17 (XTAL1), Y1.1
unnamed: C2.2, U1.16 (XTAL2), Y1.3
unnamed: C3.1, U1.6 (UCAP)
unnamed: D1.2 (A), MX1.2 (ROW)
unnamed: D2.2 (A), MX2.2 (ROW)
unnamed: D3.2 (A), MX3.2 (ROW)
unnamed: D4.2 (A), MX4.2 (ROW)
unnamed: D5.2 (A), MX5.2 (ROW)
unnamed: D6.2 (A), MX6.2 (ROW)
unnamed: D7.2 (A), MX7.2 (ROW)
unnamed: D8.2 (A), MX8.2 (ROW)
unnamed: D9.2 (A), MX9.2 (ROW)
unnamed: D10.2 (A), MX10.2 (ROW)
unnamed: D11.2 (A), MX11.2 (ROW)
unnamed: D12.2 (A), MX12.2 (ROW)
unnamed: D13.2 (A), MX13.2 (ROW)
unnamed: D14.2 (A), MX14.2 (ROW)
unnamed: D15.2 (A), MX15.2 (ROW)
unnamed: D16.2 (A), MX16.2 (ROW)
unnamed: D17.2 (A), MX17.2 (ROW)
unnamed: D18.2 (A), MX18.2 (ROW)
unnamed: D19.2 (A), MX19.2 (ROW)
unnamed: D20.2 (A), MX20.2 (ROW)
unnamed: D21.2 (A), MX21.2 (ROW)
unnamed: D22.2 (A), MX22.2 (ROW)
unnamed: D23.2 (A), MX23.2 (ROW)
unnamed: D24.2 (A), MX24.2 (ROW)
unnamed: D25.2 (A), MX25.2 (ROW)
unnamed: D26.2 (A), MX26.2 (ROW)
unnamed: D27.2 (A), MX27.2 (ROW)
unnamed: D28.2 (A), MX28.2 (ROW)
unnamed: D29.2 (A), MX29.2 (ROW)
unnamed: D30.2 (A), MX30.2 (ROW)
unnamed: D31.2 (A), MX31.2 (ROW)
unnamed: D32.2 (A), MX32.2 (ROW)
unnamed: D33.2 (A), MX33.2 (ROW)
unnamed: D34.2 (A), MX34.2 (ROW)
unnamed: D35.2 (A), MX35.2 (ROW)
unnamed: D36.2 (A), MX36.2 (ROW)
unnamed: D37.2 (A), MX37.2 (ROW)
unnamed: D38.2 (A), MX38.2 (ROW)
unnamed: D39.2 (A), MX39.2 (ROW)
unnamed: D40.2 (A), MX40.2 (ROW)
unnamed: D41.2 (A), MX41.2 (ROW)
unnamed: D42.2 (A), MX42.2 (ROW)
unnamed: D43.2 (A), MX43.2 (ROW)
unnamed: D44.2 (A), MX44.2 (ROW), MX49.2 (ROW)
unnamed: D45.2 (A), MX45.2 (ROW)
unnamed: D46.2 (A), MX46.2 (ROW), MX50.2 (ROW)
unnamed: D47.2 (A), MX47.2 (ROW)
unnamed: D48.2 (A), MX48.2 (ROW)
unnamed: J1.1 (MISO), U1.11 (PB3)
unnamed: J1.3 (SCK), U1.9 (PB1)
unnamed: J1.4 (MOSI), U1.10 (PB2)
unnamed: R2.2, U1.4 (D+)
unnamed: R3.2, U1.3 (D-)
unnamed: R4.2, U1.33 (~HWB~/PE2)
unnamed: R5.1, USB2.4 (CC1)
unnamed: R6.1, USB2.10 (CC2)
RESET: J1.5 (~RST), R1.1, SW1.2, U1.13 (~RESET)
ROW0: D1.1 (K), D2.1 (K), D3.1 (K), D4.1 (K), D5.1 (K), D6.1 (K), U1.36 (PF7)
ROW1: D14.1 (K), D15.1 (K), D16.1 (K), D17.1 (K), D18.1 (K), D19.1 (K), U1.32 (PC7)
ROW2: D27.1 (K), D28.1 (K), D29.1 (K), D30.1 (K), D31.1 (K), D32.1 (K), U1.27 (PD7)
ROW3: D39.1 (K), D40.1 (K), D41.1 (K), D42.1 (K), D43.1 (K), U1.26 (PD6)
ROW4: D7.1 (K), D8.1 (K), D9.1 (K), D10.1 (K), D11.1 (K), D12.1 (K), D13.1 (K), U1.39 (PF4)
ROW5: D20.1 (K), D21.1 (K), D22.1 (K), D23.1 (K), D24.1 (K), D25.1 (K), D26.1 (K), U1.38 (PF5)
ROW6: D33.1 (K), D34.1 (K), D35.1 (K), D36.1 (K), D37.1 (K), D38.1 (K), U1.19 (PD1)
ROW7: D44.1 (K), D45.1 (K), D46.1 (K), D47.1 (K), D48.1 (K), U1.20 (PD2)
VCC: F1.2, U2.4 (VCC), USB1.5 (VBUS), USB2.2 (VBUS), USB2.11 (VBUS)

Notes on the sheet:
Tab
Esc
Cmd
Option
Shift
Ctrl
Space 2.75
down
Enter
Dombrick means Dvorak Oriented Mechanical Breakthough Remakable Interesting Coolest Keyboard :)
Space 6.25
Right L2

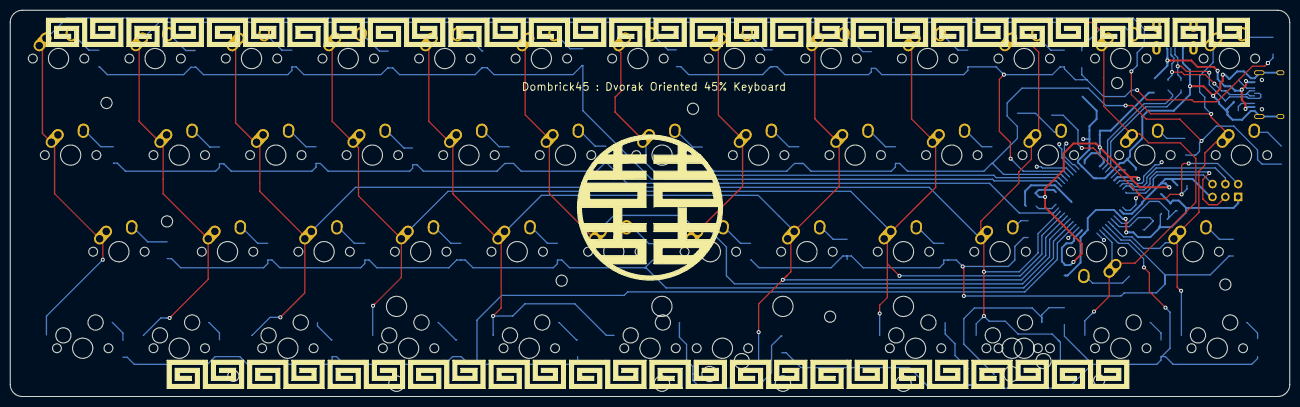
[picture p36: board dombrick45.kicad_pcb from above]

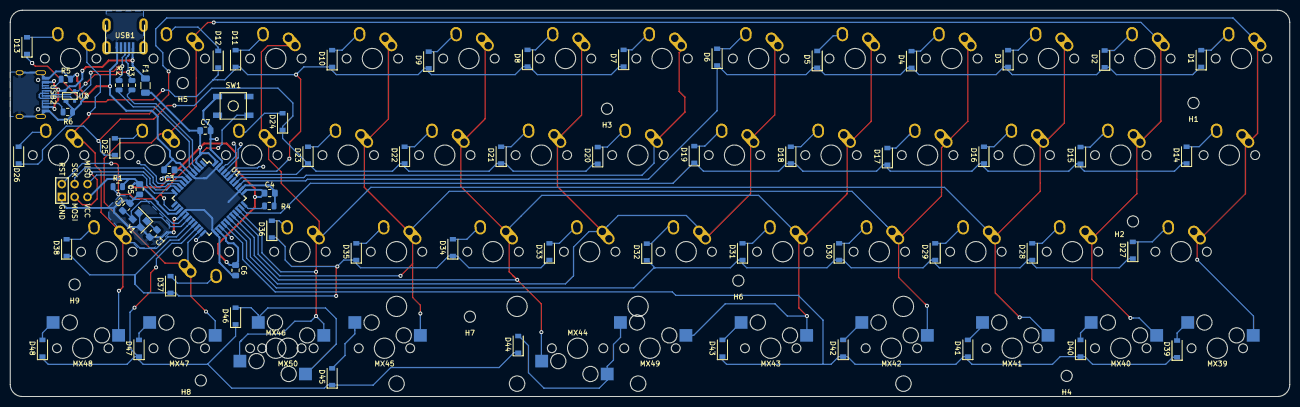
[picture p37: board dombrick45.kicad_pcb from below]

Board: 2 copper layers, 252.4 x 76.2 mm, 128 parts (78 on the bottom side), 80 nets.

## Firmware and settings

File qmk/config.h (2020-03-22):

/*
Copyright 2019 t-miyajima

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
You should have received a copy of the GNU General Public License
along with this program.  If not, see <http://www.gnu.org/licenses/>.
*/

#pragma once

#include "config_common.h"

/* USB Device descriptor parameter */
#define VENDOR_ID 0xFEED
#define PRODUCT_ID 0x0000
#define DEVICE_VER 0x0001
#define MANUFACTURER t-miyajima
#define PRODUCT dombrick45
#define DESCRIPTION Dvorak Oriented Mechanical Breakthough Remakable Interesting Coolest Keyboard

/* t-miyajima usb power settings arrenge */
#define USB_MAX_POWER_CONSUMPTION 100
#define USB_DEVICE_POWER 100

/* key matrix size */
#define MATRIX_ROWS 8
#define MATRIX_COLS 7

/*
 * Keyboard Matrix Assignments
 *
 * Change this to how you wired your keyboard
 * COLS: AVR pins used for columns, left to right
 * ROWS: AVR pins used for rows, top to bottom
 * DIODE_DIRECTION: COL2ROW = COL = Anode (+), ROW = Cathode (-, marked on diode)
 *                  ROW2COL = ROW = Anode (+), COL = Cathode (-, marked on diode)
 *
 */
#define MATRIX_ROW_PINS { F7, C7, D7, D6, F4, F5, D1, D2 }
#define MATRIX_COL_PINS { D0, D3, C6, B6, B5, B4, F6 }
#define UNUSED_PINS

/* COL2ROW, ROW2COL*/
#define DIODE_DIRECTION COL2ROW

/*
 * Split Keyboard specific options, make sure you have 'SPLIT_KEYBOARD = yes' in your rules.mk, and define SOFT_SERIAL_PIN.
 */
#define SOFT_SERIAL_PIN D0  // or D1, D2, D3, E6

// #define BACKLIGHT_PIN B7
// #define BACKLIGHT_BREATHING
// #define BACKLIGHT_LEVELS 3

// #define RGB_DI_PIN E2
// #ifdef RGB_DI_PIN
//   #define RGBLED_NUM 16
//   #define RGBLIGHT_HUE_STEP 8
//   #define RGBLIGHT_SAT_STEP 8
//   #define RGBLIGHT_VAL_STEP 8
//   #define RGBLIGHT_LIMIT_VAL 255 /* The maximum brightness level */
//   #define RGBLIGHT_SLEEP  /* If defined, the RGB lighting will be switched off when the host goes to sleep */
// /*== all animations enable ==*/
//   #define RGBLIGHT_ANIMATIONS
// /*== or choose animations ==*/
//   #define RGBLIGHT_EFFECT_BREATHING
//   #define RGBLIGHT_EFFECT_RAINBOW_MOOD
//   #define RGBLIGHT_EFFECT_RAINBOW_SWIRL
//   #define RGBLIGHT_EFFECT_SNAKE
//   #define RGBLIGHT_EFFECT_KNIGHT
//   #define RGBLIGHT_EFFECT_CHRISTMAS
//   #define RGBLIGHT_EFFECT_STATIC_GRADIENT
//   #define RGBLIGHT_EFFECT_RGB_TEST
//   #define RGBLIGHT_EFFECT_ALTERNATING
// /*== customize breathing effect ==*/
//   /*==== (DEFAULT) use fixed table instead of exp() and sin() ====*/
//   #define RGBLIGHT_BREATHE_TABLE_SIZE 256      // 256(default) or 128 or 64
//   /*==== use exp() and sin() ====*/
//   #define RGBLIGHT_EFFECT_BREATHE_CENTER 1.85  // 1 to 2.7
//   #define RGBLIGHT_EFFECT_BREATHE_MAX    255   // 0 to 255
// #endif

/* Debounce reduces chatter (unintended double-presses) - set 0 if debouncing is not needed */
#define DEBOUNCE 5

/* define if matrix has ghost (lacks anti-ghosting diodes) */
//#define MATRIX_HAS_GHOST

/* Mechanical locking support. Use KC_LCAP, KC_LNUM or KC_LSCR instead in keymap */
#define LOCKING_SUPPORT_ENABLE
/* Locking resynchronize hack */
#define LOCKING_RESYNC_ENABLE

/* If defined, GRAVE_ESC will always act as ESC when CTRL is held.
 * This is userful for the Windows task manager shortcut (ctrl+shift+esc).
 */
// #define GRAVE_ESC_CTRL_OVERRIDE

/*
 * Force NKRO
 *
 * Force NKRO (nKey Rollover) to be enabled by default, regardless of the saved
 * state in the bootmagic EEPROM settings. (Note that NKRO must be enabled in the
 * makefile for this to work.)
 *
 * If forced on, NKRO can be disabled via magic key (default = LShift+RShift+N)
 * until the next keyboard reset.
 *
 * NKRO may prevent your keystrokes from being detected in the BIOS, but it is
 * fully operational during normal computer usage.
 *
 * For a less heavy-handed approach, enable NKRO via magic key (LShift+RShift+N)
 * or via bootmagic (hold SPACE+N while plugging in the keyboard). Once set by
 * bootmagic, NKRO mode will always be enabled until it is toggled again during a
 * power-up.
 *
 */
//#define FORCE_NKRO

/*
 * Magic Key Options
 *
 * Magic keys are hotkey commands that allow control over firmware functions of
 * the keyboard. They are best used in combination with the HID Listen program,
 * found here: https://www.pjrc.com/teensy/hid_listen.html
 *
 * The options below allow the magic key functionality to be changed. This is
 * useful if your keyboard/keypad is missing keys and you want magic key support.
 *
 */

/* key combination for magic key command */
/* defined by default; to change, uncomment and set to the combination you want */
// #define IS_COMMAND() (get_mods() == MOD_MASK_SHIFT)

/* control how magic key switches layers */
//#define MAGIC_KEY_SWITCH_LAYER_WITH_FKEYS  true
//#define MAGIC_KEY_SWITCH_LAYER_WITH_NKEYS  true
//#define MAGIC_KEY_SWITCH_LAYER_WITH_CUSTOM false
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

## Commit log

2019-09-29 create kicad project
    only create project
    [dombrick45.kicad_pcb, dombrick45.sch]
2019-10-05 2019-10-04
    2019-10-04 ai10さんブログの演習途中
    [dombrick45.sch]
2019-10-06 2019-10-06 tutorial
    hobo kansei
    [dombrick45.kicad_pcb, dombrick45.sch]
2019-10-06 2019-10-06 tutorial last
    [dombrick45-B_Cu.gbl, dombrick45-B_Mask.gbs, dombrick45-B_SilkS.gbo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]
2019-10-08 dombrick45 sematic to pcb tochuu
    [dombrick45.kicad_pcb, dombrick45.sch]
2019-10-09 2019-10-10 keysw connect
    [dombrick45.kicad_pcb, dombrick45.sch]
2019-10-11 2019-10-12 PBC ver0.1
    [dombrick45.kicad_pcb, dombrick45.sch]
2019-10-12 2019-10-12 haisen bishuusei
    [dombrick45.kicad_pcb]
2019-10-12 2019-10-12 advice itadaita ato
    [dombrick45.kicad_pcb]
2019-10-13 2019-10-14 SPI toridashi and dombri mark
    [dombrick45.kicad_pcb, dombrick45.sch]
2019-10-20 2019-10-21 usb-c impl, gnd filled and silk design completed.
    [dombrick45.kicad_pcb, dombrick45.sch]
2019-10-21 2019-10-22 hobo OK
    [dombrick45.kicad_pcb, dombrick45.sch]
2019-10-23 2019-10-23 pcb to usb-c buhin hacchuu go
    [dombrick45-B_Cu.gbl, dombrick45-B_Mask.gbs, dombrick45-B_SilkS.gbo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]
2020-03-22 キー配列の書き込み方法を記載
2020-03-22 ファームウェア書き込み方法を追記

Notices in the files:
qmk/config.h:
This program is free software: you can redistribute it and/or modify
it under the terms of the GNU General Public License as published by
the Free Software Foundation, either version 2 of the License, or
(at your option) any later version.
